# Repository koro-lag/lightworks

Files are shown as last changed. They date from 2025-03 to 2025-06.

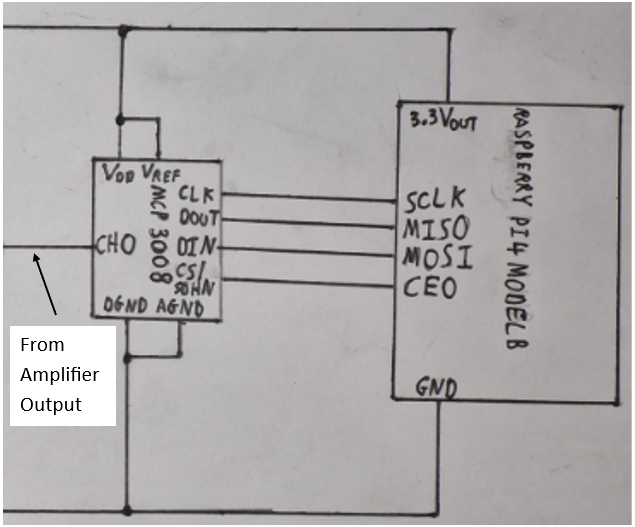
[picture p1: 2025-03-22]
Instructions/Figure 6.png

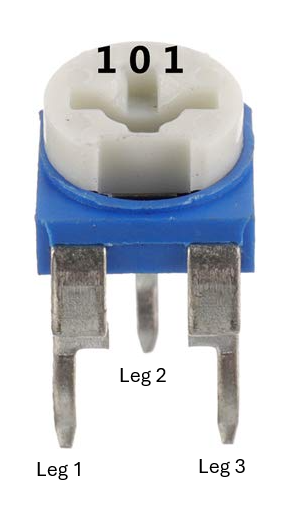
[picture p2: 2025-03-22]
Instructions/Figure 2.png

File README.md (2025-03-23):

# NAVIGATION
*Below are descriptions of the contents of each file on this repository*

### Source Code
- 'Light App.py' *(contains main program with analytics and forecast module)*

- 'LDT Code.py' *(code for Live Dimming Technology)*

- 'Dummy Duty Cycle Generator.py' *(random mark to space ratio generator to test live graphs)*

- 'sensor_data.csv' *(file that stores and updates mark to space ratio values for live graphs)*

### Software & Hardware List
- 'Components List.xlsx' *(spreadsheet contains more readable version of materials used for project)*

### Instructions
- 'Figure 1.png' to 'Figure 8.png' *(figures mentioned for instructions question on the submission form)*

- 'Instructions (with embedded figures).docx' *(document contains more readable version of instructions)*

### Design
- 'Lamp RIG.stl' *(3D print model of rig for circuitry of lamp)*

### Research
- 'Forecast Model Specification.docx' *(contains cited research into the program’s constants and formulas for calculations)*

- 'LDT Input Circuit Diagram.docx' *(contains in depth explanation of circuit design)*

- 'LDT Output Circuit Diagram.docx' *(contains in depth explanation of circuit design)*

# PROJECT SUMMARY

The Light-Emitting Diode is one of the greatest inventions of the 20th century. Since the early 2000s, LED light bulbs have been praised for their lifespan and energy-saving capabilities—they use at least 75% less energy and last up to 25 times longer than incandescent bulbs.

Despite this, LEDs have still only been adopted by 18% of all UK households. We attribute this poor adoption to society’s lack of information and understanding around lighting. This ignorance has consequences: unnecessary energy waste and astronomically high lighting bills.

Another issue regarding lighting is humans themselves. Even if LEDs were implemented nationwide, we would still have a relatively high electricity consumption due to excess lighting and keeping the lights on when they aren’t needed.

Our project has been dedicated to finding a solution to these issues—approaching it in two ways. We have developed a program that aims to promote energy savings by making consumers more conscious of their energy use. We have also innovated a new mechanism called LDT (Live Dimming Technology) that we estimate can make LEDs around 30% more efficient.

Below, we speak briefly about both solutions.

### Live Dimming Technology

We tackled the issue of excess lighting by automatically adjusting light according to ambient conditions. In the past, this typically involved using a sensor that measured external brightness and fed a PWM controller that adjusted the LED output. A limitation of this technology is that to avoid positive feedback, designers usually must physically shield the sensor from the LED. This reduces the uses of this technology – many spaces do not have naturally unlit areas.

LDT differs from current-day technology by having the LED temporarily turned off whenever readings are taken. We fully prevent a positive feedback loop – without shielding sensors or having energy-intensive filtering algorithms.

We have demonstrated this technology in the footprint of a lamp and are working toward fitting it into a standard light bulb.

### The Program

Our program has been developed to work alongside our live dimming technology. It directly tackles the lack of information around lighting by providing interactive tools to make consumers more conscious of their lighting use. It also provides estimates of energy/cost savings and CO2e prevention if lighting systems used our technology.

The Program consists of two modules. The first module, “Analytics”, provides real-time data on several statistics of a lighting system, such as total power consumption, energy consumption, CO2e emissions, and electricity saved. Currently, it is only based on a single LED, and we are currently working on using it with systems of LEDs. This tool would be beneficial for commercial use, giving shopping malls and offices better insight into their energy use.

The second module, “Forecast”, is a prediction model that we have developed for households to demonstrate the tremendous energy savings achieved when switching from halogens, incandescent, and CFL light bulbs to LEDs. It also shows the further energy savings achieved if all the light bulbs used LDT.

# VIDEOS
## 5 Minute Presentation
Presentation video (https://youtu.be/xpUQCLLk9Fk)

## Demonstration
Demonstration video (https://youtu.be/OyPKLj0iM8w)

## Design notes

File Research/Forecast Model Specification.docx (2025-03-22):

COLLECTED DATA FOR MODEL

Relating to lightbulb / energy use

1. Energy cost per kWh: 27.03 pence per kWh (Q2 2025 price cap, includes VAT) Source: Energy price cap | Ofgem (https://www.ofgem.gov.uk/energy-price-cap)
2. CO₂ emissions per kWh: 0.207074 kg CO₂e per kWh (2023 UK grid average) Source: Greenhouse gas reporting: conversion factors 2023 - GOV.UK (https://www.gov.uk/government/publications/greenhouse-gas-reporting-conversion-factors-2023), condensed set, under “UK electricity”
3. Hours a day a lightbulb is used: 3.9 hours a day (Table 5, calculated by taking mean of medium)

Source: Energy Follow-Up Survey 2011 Report 8: Lighting (https://assets.publishing.service.gov.uk/media/5a7c260440f0b645ba3c6ff3/8_Lighting.pdf)

4. Average lightbulbs per household: 34 bulbs (estimated, UK households) Source: Is Switching to LED Bulbs Worth It? - Evergreen Energy (https://www.evergreenenergy.co.uk/led-lights/why-you-should-make-the-switch-to-led/)
5. Average power ratings (W):
- Incandescent: 60W
- Halogen: 45W
- Compact Fluorescent (CFL): 15W
- LED: 8W

Source: Average Wattage of a Light Bulb: A Comprehensive Guide (https://www.ukenergywatch.org/how-many-watts-lightbulb-use/)

6. Lightbulb type distribution:
  - Incandescent: 5%
  - Halogen: 10%
  - Compact Fluorescent (CFL): 10%
  - LED: 75%

Disclaimer: We could not find any modern data regarding these statistics.

These percentages are estimations guided by the predictions / trends outlined by following sources:

Microsoft Word - Revised Lighting Report 070414b (https://assets.publishing.service.gov.uk/media/5a7dbc54e5274a5eaea66049/Lighting_Report.pdf)

More on the DOE's 2020 US Lighting Market Characterization - US Lighting Trends (https://www.uslightingtrends.com/news/more-on-the-does-2020-us-lighting-market-characterization/)

Relating to Household Data (UK)

1. Average usable floor space per house:

97m² (2.11, 2021)

Source: English Housing Survey 2021 to 2022: headline report - GOV.UK (https://www.gov.uk/government/statistics/english-housing-survey-2021-to-2022-headline-report/english-housing-survey-2021-to-2022-headline-report)

2. Average people per household: 2.2 people (2023-2024 English Housing Survey) Source: Chapter 1: Profile of households and dwellings - GOV.UK (https://www.gov.uk/government/statistics/chapters-for-english-housing-survey-2023-to-2024-headline-findings-on-demographics-and-household-resilience/chapter-1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)

PROGRAM / ALGORITHM

Constants

DAYS_IN_YEARS = 365.25

HOURS_PER_DAY = 3.9

COST_PER_KWH = 0.2703

CO2_PER_KWH = 0.207074

INCANDESCENT_POWER = 60

HALOGEN_POWER = 45

CFL_POWER = 15

LED_POWER = 8

Variables

incandescent_count = int

halogen_count = int

cfl_count = int

led_count = int

room_count = int

people_count = int

For annual light usage estimate for census

Proportioned lightbulb type distribution with 34 lightbulbs

C_INCANDSCENT_COUNT = 2

C_HALOGEN_COUNT = 3

C_CFL_COUNT = 3

C_LED_COUNT = 26

C_PEOPLE_COUNT = 2.4

C_ROOM_COUNT = 5 (Living room, kitchen, 2 bedrooms, bathroom)

Calculation of Annual Energy Consumption

ΣW = (nI)(WI) +(nH)(WH) + (nCF)(WCF) + (nLED)(WLED)

Where n = no. of, W = Power (W) of, I = Incandescent, H = Halogen, CF = Compact Fluorescent, LED = Light Emitting Diode

ENERGYAnnual = (ΣW/1000)(hours used per day)(days in years)(people / no. rooms)

Calculation of Estimated Annual Cost

COSTAnnual = (EAnnual)(Cost per kWh)

Calculation of Estimated Annual CO2e Emissions

CO2Annual = (EAnnual)(CO₂e per kWh)

ANNUAL LIGHT USAGE FORECAST MODEL SPECIFICATION

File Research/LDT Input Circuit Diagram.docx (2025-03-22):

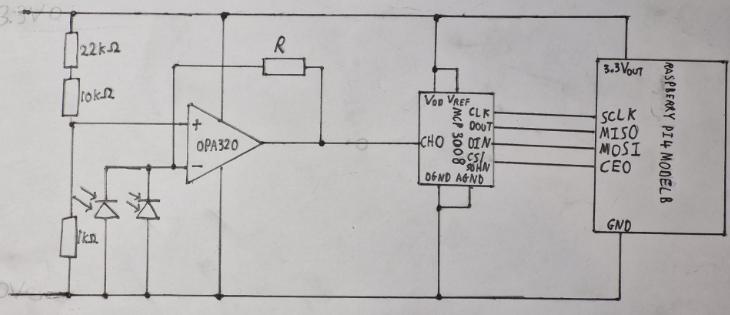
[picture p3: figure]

The program written allows the Pi to read the digital value input into it.

This is the MCP 3008 ADC. The input analogue voltage signal is converted into a 10-bit digital value, taking any value between 0 and 1023, and this value is then input into the Pi, allowing the Pi to process the light intensity information from outside.

VOUT

These are the photodiodes. I have used 2 in parallel rather than just one, as I discovered that using more photodiodes in series increases the ‘sensitivity’, or gain, of the amplifier, meaning that the amplifier saturates earlier.

This is a potential divider. Using resistors in series, I have produced a constant input voltage, which is VOUTMIN , into the OPA320.

This is the circuit diagram for the input section of the circuit diagram. To summarise, the photodiodes consume light energy and produce current from it. The OPA320 designed as a transimpedance amplifier then converts this into an analogue voltage signal. This is input into the MCP 3008 ADC, which converts the input signal into a 10-bit ADC value, which is then input into the Pi via various connections.

This is a potentiometer. I have labelled it as ‘R’ rather than with a constant resistor value as the resistance is variable and can be changed during testing and for final changes.

The Raspberry Pi acts as a power supply for the input part of the circuit. I use the 3.3V output pin as the positive power rail, and the GND pin as the 0V power rail.

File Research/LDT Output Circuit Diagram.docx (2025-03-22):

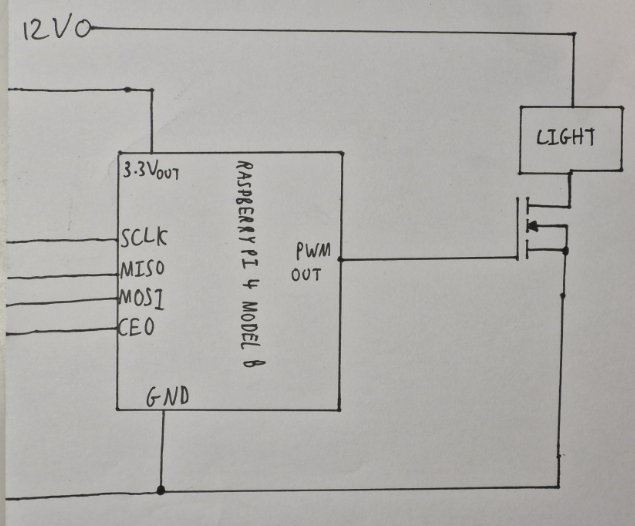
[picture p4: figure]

I am joining the grounds, or 0V power rails, of the Raspberry Pi and the circuit with the light output and the 12V supply so that the MOSFET input is not left floating relative to the rest of the circuit. In other words, if the input to the MOSFET does not have the same 0V reference as the MOSFET itself, the MOSFET will not be able to determine the voltage input into it due to a lack of a reference voltage.

I am using a 12V supply to power the light output of our circuit. The Raspberry Pi cannot provide enough current to light the lamp and so an external power source is needed.

This transistor, an N-Channel MOSFET, is needed as the Raspberry Pi outputs source far too low amounts of current compared to the current needed for the lamp to light. The transistor is a power amplifier, allowing the lamp to light when the Pi PWM output is high.

This is the light output of our circuit. Its brightness will vary according the brightness of the surroundings via PWM.

The PWM Output is the GPIO port that outputs a square wave with different duty cycles which will vary the average brightness of the lamp accordingly.

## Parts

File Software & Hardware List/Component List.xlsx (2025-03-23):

HARDWARE |  |  |  |  |  | SOFTWARE |  |  |  | KEY |  | NOTES
KEY | Part Name | Quantity | Place of Purchase | Link | Price (£) | KEY | Library Name | Link | Cost |  | Needed for Lamp | Cost per unit is known
 |  |  |  |  |  |  | Adafruit_MCP3008 | https://github.com/adafruit/Adafruit_MCP3008 | 0 |  | Cost esimated | Cost per unit is unknown, estimated by dividng total cost of bulk buy by no. components or cost of material used
 | OPA320 Operational Amplifier | 1 | CPC Farnell | https://cpc.farnell.com/texas-instruments/opa320aidbvt/op-amp-cmos-20mhz-5sot23/dp/SC17216|%20cpc | 1.87 |  | matplotlib | https://matplotlib.org/ | 0 |  | Origin/brand/cost unknown | Material found/not bought that could not be traced to an original place of purchase, cost has been estimated
 | OSRAM SFH213 Photodiode | 2 | CPC Farnell | https://cpc.farnell.com/osram/sfh213/photodiode/dp/SC07707?st=osram | 0.96 |  | Customtkinter | https://customtkinter.tomschimansky.com/ | 0
 | Resistors 56Ω | 4 | Bojack (Via Amazon) | https://www.amazon.co.uk/BOJACK-Values-Resistor-Resistors-Assortment/dp/B08FD1XVL6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 | 0.04 |  | pandas | https://pandas.pydata.org/ | 0 |  | Needed for Demonstration | Additional material needed to demonstrate our product working (not actually needed during normal use)
 | Resistor 1kΩ | 1 | Bojack (Via Amazon) | https://www.amazon.co.uk/BOJACK-Values-Resistor-Resistors-Assortment/dp/B08FD1XVL6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 | 0.01 |  |  |  |  |  | Needed for App
 | Resistor 10kΩ | 1 | Bojack (Via Amazon) | https://www.amazon.co.uk/BOJACK-Values-Resistor-Resistors-Assortment/dp/B08FD1XVL6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 | 0.01
 | Resistor 22kΩ | 1 | Bojack (Via Amazon) | https://www.amazon.co.uk/BOJACK-Values-Resistor-Resistors-Assortment/dp/B08FD1XVL6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 | 0.01
 | 500kΩ Potentiometer | 1 | Bojack (Via Amazon) | https://www.amazon.co.uk/BOJACK-Variable-Resistor-Potentiometer-Assortment/dp/B07WRWHCMC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 | 0.07
 | 1MΩ Potentiometer | 1 | Bojack (Via Amazon) | https://www.amazon.co.uk/BOJACK-Variable-Resistor-Potentiometer-Assortment/dp/B07WRWHCMC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 | 0.07
 | MCP 3008 8-Channel 10-Bit ADC | 1 | The Pi Hut | https://thepihut.com/products/adafruit-mcp3008-8-channel-10-bit-adc-with-spi-interface | 3.30
 | Breadboard | 2 | Rapid | https://www.rapidonline.com/k-h-kh-102-prototyping-breadboard-390-tie-points-34-0650 | 20.60
 | LED | 1 | Amazon | https://www.amazon.co.uk/dp/B07HFRZDRN | 5.25
 | Jumper Wires M-M | 12 | Rapid | https://www.rapidonline.com/rapid-jw-d1-mm-jumper-wires-dupont-cable-m-m-26awg-1-pin-2-54mm-pitch-15cm-pk10-34-0677 | 3.86
 | N-Channel MOSFET | 1 | Rapid | https://www.rapidonline.com/stp36nf06-mosfet-n-60v-30a-47-0207 | 0.23
 | Lamp Case Lid | 1 | - | - | 1.50
 | Lamp Case Bottom | 1 | - | - | 0.80
 | Filament for 3D Print | 110g | Amazon | https://www.amazon.co.uk/eSUN-Filament-Dimensional-Accuracy-Printing/dp/B086GTG1D8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 | 2.31
 | Ford Transit Van Interior Dome Light | 1 | Ali Express | https://www.aliexpress.com/item/1005008228479744.html?src=google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 | 4.14
 | Variable Power Supply | 1 | Amazon | https://www.amazon.co.uk/LOGNWEI-Variable-4-Digital-%EF%BC%8CVariable-Electroplating/dp/B07MDVTTM7 | 39.99
 | Fixed Power Supply | 1 | Amazon | https://www.amazon.co.uk/100-240V-Converter-Adapter-Portable-Approved/dp/B019RO949C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 | 8.99
 | Price of Lamp (£) |  |  |  | 38.58
 | Total Price (including demonstration equipment not part of lamp) (£) |  |  |  | 94.01

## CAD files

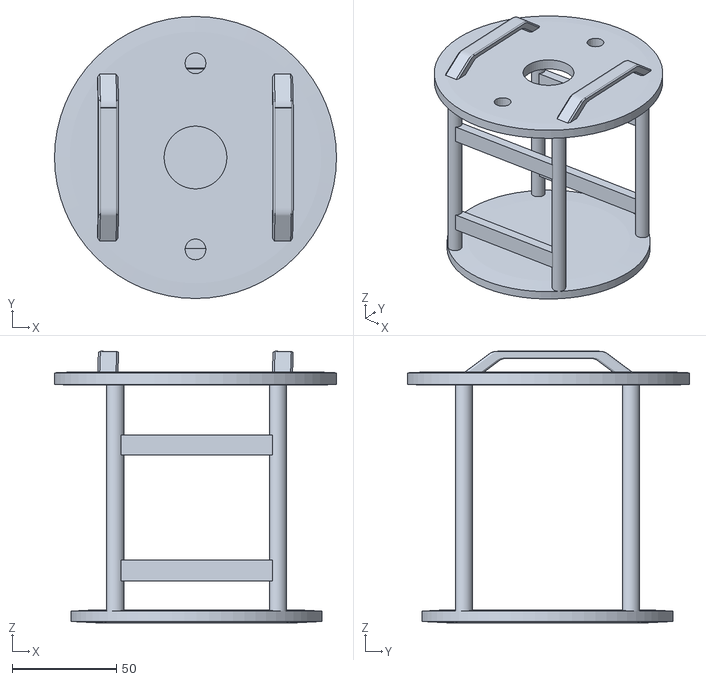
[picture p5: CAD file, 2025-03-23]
Design/Raspberry Pi RIG.stl
135.0 x 135.0 x 130.0

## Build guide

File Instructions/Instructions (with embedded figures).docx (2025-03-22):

Wiring and Construction

Refer to Figures 1 to 8 on our GitHub throughout this process

Light Sensing Unit:

1. Take a breadboard, with a positive and a negative power rail.
2. Set up the potential divider network using the 22k Ω, 10k Ω and 1k Ω resistors (as seen in Figure 1), and connect the output to the non-inverting input of the amplifier (OPA320).
3. Connect together the cathodes and anodes of the 2 photodiodes. Connect the cathodes to the inverting input and the anodes to the 0V power rail. (Figure 1)
4. Use 2 potentiometers of values 1M Ω and 500k Ω. Connect ‘Leg 1’ of the 1M Ω potentiometer to the amplifier output pin (Figures 1, 2), and ‘Leg 1’ of the 500k Ω potentiometer to ‘Leg 2’ of the 1M Ω potentiometer, and ‘Leg 2’ of the 500k Ω potentiometer to the inverting input of the amplifier (Figures 1, 2 and 3).
5. Connect the positive supply pin of the amplifier to the positive power rail, and the negative supply pin to the 0V power rail.

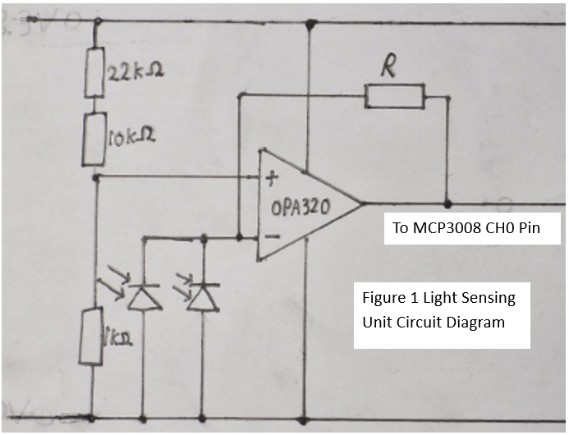
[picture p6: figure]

6. Connect the output pin of the amplifier to CH0 of the MCP 3008 (Figure 3, 6).

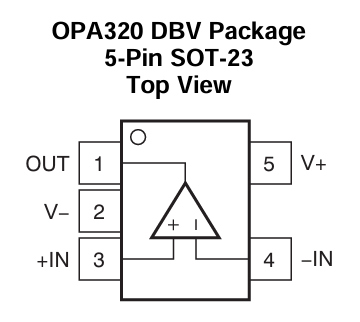
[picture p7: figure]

Figure 1

Figure 3

Figure 2

Figure 2

ADC Unit:

Connect, referring to Figures 4, 5 and 6:

1. MCP3008 VDD to Positive Power Rail.
2. MCP3008 VREF to Positive Power Rail.
3. MCP3008 AGND to 0V Power Rail.
4. MCP3008 DGND to 0V Power Rail.
5. MCP3008 CLK to Raspberry Pi SCLK.
6. MCP3008 DOUT to Raspberry Pi MISO.
7. MCP3008 DIN to Raspberry Pi MOSI.
8. MCP3008 CS/SHDN to Raspberry Pi CE0.
9. Connect Raspberry Pi 3.3V Output Pin to Positive Power Rail.

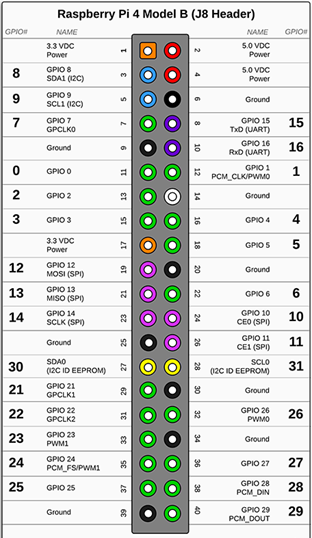
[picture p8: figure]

Figure 6

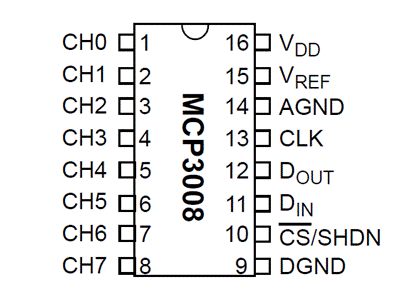
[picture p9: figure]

Figure 4

Output Light Unit:

Figure 5

1. Connect the PWM Output Pin of the Pi to the Gate of the MOSFET (Figures 7, 8).
2. Arrange 4 x 56 Ω resistors in parallel, with both ends of all the resistors joined together. Connect one end of the network to the drain of the transistor and the other end of the network to the negative end of the spotlight (Figure 7, 8).
3. Connect the positive end of the spotlight the positive power rail of the 12V supply. (Figure 7).
4. Connect the 0V power rail of the 12V supply to the source of the transistor, as well as to the GND, or Ground, Pin of the Raspberry Pi. (Figures 4, 7).

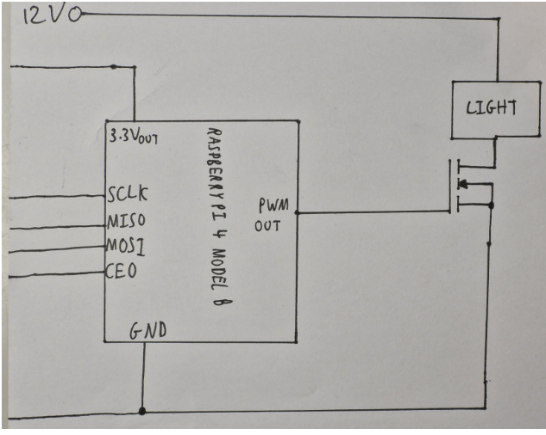
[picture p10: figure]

Figure 8

Figure 7

Software

1. Install the following libraries onto the Raspberry Pi:
- Adafruit_MCP3008
- Customtkinter
- Matplotlib
- Pandas
2. Run LDT Code.py program parallel to Light App.py
3. If lamp is not responding accurately to the environment:
- Calibrate sensitivity by changing the values in the selection ranges.
- Calibrate the output by changing the return values.

INSTRUCTIONS DOCUMENT (WITH EMBEDDED FIGURES)

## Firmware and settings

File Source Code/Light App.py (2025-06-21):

'''Imports'''
# For App
import customtkinter as ctk
from matplotlib.backends.backend_tkagg import FigureCanvasTkAgg
import csv

# For Live Graphs
import pandas as pd
import matplotlib.pyplot as plt

'''Initialise Variables & Constants'''

DAYS_IN_YEARS = 365.25
HOURS_PER_DAY = 4.0 # Hours per day lights are used
COST_PER_KWH = 27.03 # Current cost of electricty p/kWh
CO2_PER_KWH = 0.207074 # CO2 equivalent kg/kWh

# WATTS of each lightbulb type
INCANDESCENT_POWER = 60
HALOGEN_POWER = 45
CFL_POWER = 15
LED_POWER = 8

MAX_VOLTAGE = 12
CURRENT = 0.2 # Current going to LDT light circuit
INTERVAL = 5 # Graph updates every x seconds

C_INCANDSCENT_COUNT = 2
C_HALOGEN_COUNT = 3
C_CFL_COUNT = 3
C_LED_COUNT = 26
C_PEOPLE_COUNT= 2
C_ROOM_COUNT =  5 # Living room, kitchen, 2 bedrooms, bathroom

# For Analytics
energy_with_ldl = 0.0
energy_without_ldl = 0.0
energy_savings = 0.0
co2_emissions = 0.0
time_passed = 0.0

# Control Module Subprograms ---------------------------------------------------------------------------------

with open('control_module.csv', "w", newline='') as file:
    csv_writer = csv.DictWriter(file, fieldnames = ["mode", "dc"])
    csv_writer.writeheader()

current_mode = 'focus'

def control(mode_chosen):
    global current_mode
    current_mode = mode_chosen.lower()

    if current_mode in ('focus', 'ambience'):
        with open('control_module.csv', 'a', newline='') as file:
            csv_writer = csv.DictWriter(file, fieldnames=["mode", "dc"])
            csv_writer.writerow({
                'mode': current_mode,
                'dc': 0                   # ← changed key from 'duty_cycle' to 'dc'
            })

def manual_value(slider_value):
    # only do something if we're in Manual mode
    if current_mode == "manual":
        with open('control_module.csv', 'a', newline='') as file:
            csv_writer = csv.DictWriter(file, fieldnames=["mode", "dc"])
            csv_writer.writerow({
                'mode': current_mode,
                'dc': slider_value        # ← changed key from 'duty_cycle' to 'dc'
            })

# Forecast Model ---------------------------------------------------------------------------------------------

def forecast_model(*args): # Converting widget entries to integers, defaulting if invalid input

    try:
        num_room = int(room_count.get())
    except ValueError:
        num_room = 1
    try:
        num_people = int(people_count.get())
    except ValueError:
        num_people = 1
    try:
        num_incandescent = int(incandescent_count.get())
    except ValueError:
        num_incandescent = 0
    try:
        num_halogen = int(halogen_count.get())
    except ValueError:
        num_halogen = 0
    try:
        num_cfl = int(cfl_count.get())
    except ValueError:
        num_cfl = 0
    try:
        num_led = int(led_count.get())
    except ValueError:
        num_led = 0

    total_watts = (num_incandescent)*(INCANDESCENT_POWER) + (num_halogen)*(HALOGEN_POWER) + (num_cfl)*(CFL_POWER) + (num_led)*(LED_POWER)
    annual_energy = (total_watts/1000)*(HOURS_PER_DAY)*(DAYS_IN_YEARS)*(num_people/num_room)
    annual_cost = (annual_energy)*(COST_PER_KWH)
    annual_co2 = (annual_energy)*(CO2_PER_KWH)

    ldt_total_watts = (num_incandescent + num_halogen + num_cfl + num_led)*(LED_POWER*0.7)
    ldt_annual_energy = (ldt_total_watts/1000)*(HOURS_PER_DAY)*(DAYS_IN_YEARS)*(num_people/num_room)
    ldt_annual_cost = (ldt_annual_energy)*(COST_PER_KWH)
    ldt_annual_co2 = (ldt_annual_energy)*(CO2_PER_KWH)

    current_electricty_usage.configure(text = f"Electricty Usage = {annual_energy:.3g} kWh")
    current_light_bill.configure(text = f"CO2e Emissions = {annual_cost:.2f} kg")
    current_co2_emissions.configure(text = f"Light Electricty Bill = £{annual_co2:.2f}")

    ldt_electricty_usage.configure(text = f"Electricty Usage = {(ldt_annual_energy):.3g} kWh")
    ldt_light_bill.configure(text = f"CO2e Emissions = {(ldt_annual_cost):.2f} kg")
    ldt_co2_emissions.configure(text = f"Light Electricty Bill = £{(ldt_annual_co2):.2f}")

def reset_to_census():

    room_count.set(f"{C_ROOM_COUNT}")
    people_count.set(f"{C_PEOPLE_COUNT}")
    incandescent_count.set(f"{C_INCANDSCENT_COUNT}")
    halogen_count.set(f"{C_HALOGEN_COUNT}")
    cfl_count.set(f"{C_CFL_COUNT}")
    led_count.set(f"{C_LED_COUNT}")

    forecast_model()

# Analytics Graphs & Stats -----------------------------------------------------------------------------------

''' Power Consumption over Time'''

power_consumption_graph, ax_1 = plt.subplots()
plt.style.use('seaborn-v0_8')

def update_power_consumption_graph():
    data = pd.read_csv('sensor_data.csv')
    
    time = data['time'][-20:]
    power = (MAX_VOLTAGE * CURRENT * data['duty_cycle'])[-20:]
    
    ax_1.clear()
    ax_1.set_xlabel('Time')
    ax_1.set_ylabel('Power Consumption (W)')
    ax_1.plot(time, power)
    ax_1.set_xlim(time.iloc[0], time.iloc[-1]) # When too many data points, graph starts discarding older ones

    if len(time) > 6: # Dynamically adjust the x-axis if it gets too crowded
        step = max(1, len(time) // 6)
        ax_1.set_xticks(range(0, len(time), step))
        ax_1.set_xticklabels(time[::step])
    else:
        ax_1.set_xticks(range(len(time)))
        ax_1.set_xticklabels(time)
    
    power_consumption_canvas.draw()
    
    window.after(INTERVAL * 1000, update_power_consumption_graph)

''' Energy Used over Time '''

energy_consumption_graph, ax_2 = plt.subplots()
plt.style.use('seaborn-v0_8')

def update_energy_consumption_graph():
    global energy_with_ldl
    global energy_without_ldl
    
    data = pd.read_csv('sensor_data.csv')

    energy_with_ldl += (MAX_VOLTAGE * CURRENT * (1 - data.iloc[-1]['duty_cycle']) * INTERVAL / 3600) # E = I * V * t * (J to Wh conversion) * Duty Cycle (to get average V)
    energy_without_ldl += (MAX_VOLTAGE * CURRENT) * (INTERVAL / 3600) # E = I * V * t * (J to Wh conversion)

    ax_2.clear()
    ax_2.bar(['With LDL', 'Without LDL'], [energy_with_ldl, energy_without_ldl])
    ax_2.set_ylabel('Watt-Hour (Wh)')

    # Set the initial y-axis to 10 (for visual appeal)
    initial_y_max = 3
    
    # Dynamically adjust the y-axis if the data exceeds the initial range
    max_value = max(energy_with_ldl, energy_without_ldl)
    if max_value > initial_y_max:
        ax_2.set_ylim(bottom=0, top=max_value + 5) 
    else:
        ax_2.set_ylim(bottom=0, top=initial_y_max) 

    energy_consumption_canvas.draw()

    window.after(INTERVAL * 1000, update_energy_consumption_graph)

''' Estimated Cost Savings & CO2 Emissions'''
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

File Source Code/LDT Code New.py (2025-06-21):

#Imports for using GPIO and using MCP_3008
import RPi.GPIO as GPIO
import Adafruit_GPIO.SPI as SPI
import Adafruit_MCP3008

#Imports for csv  
from datetime import datetime 
import csv
import time 
import pandas as pd

#Initialising the GPIO port we use
GPIO.setmode(GPIO.BCM)
GPIO.setup(21, GPIO.OUT) 

led = GPIO.PWM(21, 500) #Output channel set to GPIO 21 and PWM freuquency set to 500 Hz
led.start(0) #LED starts as OFF 

#Initialising the ADC 
SPI_PORT = 0
SPI_DEVICE = 0
mcp = Adafruit_MCP3008.MCP3008(spi=SPI.SpiDev(SPI_PORT, SPI_DEVICE))

modeSetting = pd.read_csv("control_module.csv")
mode = modeSetting.iloc[0,-1] #Reading last value of first column?

csvFileName = "sensor_data.csv" #CSV file is named sensor_data
fieldNames = ["time", "duty_cycle"] #Row headings are 'time' and 'duty_cycle' respectively

def avgADC(samples = 5): #Samples = 5 means we take 5 readings when this function is called
    readings = [] #We store the readings in the array
    
    led.ChangeDutyCycle(0) #The LED is set to OFF to prevent positive feedback loop
    time.sleep(0.005)

    #During the iteration we append the real time readings to the array
    for _ in range(samples):
        readings.append(mcp.read_adc(0))
        time.sleep(0.001) 
        
    return sum(readings)/len(readings) #We return a calculated average

def pwmAmbience(avgADC):
    #Subject to change depening on location
    if 0 < avgADC < 200:
        return 60
    elif 201 < avgADC < 400:
        return 40
    else: 
        return 0

def pwmFocus(avgADC):
    #Subject to change depening on location
    if 0 < avgADC < 200:
        return 100
    elif 201 < avgADC < 400:
        return 70
    else: 
        return 50
    
def manualMode():
    modeSetting = pd.read_csv("control_module.csv") 
    dc = modeSetting.iloc[1,-1]
    return dc


with open(csvFileName, 'a', newline="") as file:
    csv_writer = csv.DictWriter(file, fieldnames=fieldNames)

    try:
        while True:
            if mode == "ambience":
                avgADCValue = avgADC()
                dc = pwmAmbience(avgADCValue)
                led.ChangeDutyCycle(dc) #Changing LED PWM according to ambiance 
                time.sleep(0.0000001)
            elif mode == "focus":
                avgADCValue = avgADC()
                dc = pwmFocus(avgADCValue)
                led.ChangeDutyCycle(dc) #Changing LED PWM according to ambiance 
                time.sleep(0.0000001)
            else: 
                manualMode()
                led.ChangeDutyCycle(dc) #Changing LED PWM according to ambiance 
                time.sleep(0.0000001)

            currTime = datetime.now().strftime("%H:%M:%S") #When updating the file we include the current time
            
            info = {
                "time": currTime,
                "duty_cycle": (dc/100)
            }
            csv_writer.writerow(info) #Updating the file for communication with our application
            
            print(currTime, dc/100) #Ouput the time and PWM into terminal for testing
            
            file.flush() #Clear buffer for the file
            time.sleep(5) #We only update the file every 5 seconds


    #Stop the program and turn of the LED
    except KeyboardInterrupt:
        led.stop()
        GPIO.cleanup() 

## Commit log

2025-03-22 Update and rename Dummy Duty Cycle Data.py to Dummy Duty Cycle Generator.py
    Generates random duty cycle values to test app (when not connected to Raspberry Pi)
2025-03-22 Update and rename sensor_data.csv to Source Code/sensor_data.csv
    [sensor_data.csv]
2025-03-22 Rename Component List.xlsx to Hardware & Software/Component List.xlsx
    [Component List.xlsx]
2025-03-22 Rename Component List.xlsx to Software & Hardware List/Components List.xlsx
    [Components List.xlsx]
2025-03-23 Rename Raspberry Pi RIG.stl to Design/Raspberry Pi RIG.stl
    [Raspberry Pi RIG.stl]
